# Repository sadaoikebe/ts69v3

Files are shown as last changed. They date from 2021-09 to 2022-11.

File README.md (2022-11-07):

# TS69V3 親指シフト入力に使える一体型 65% キーボード

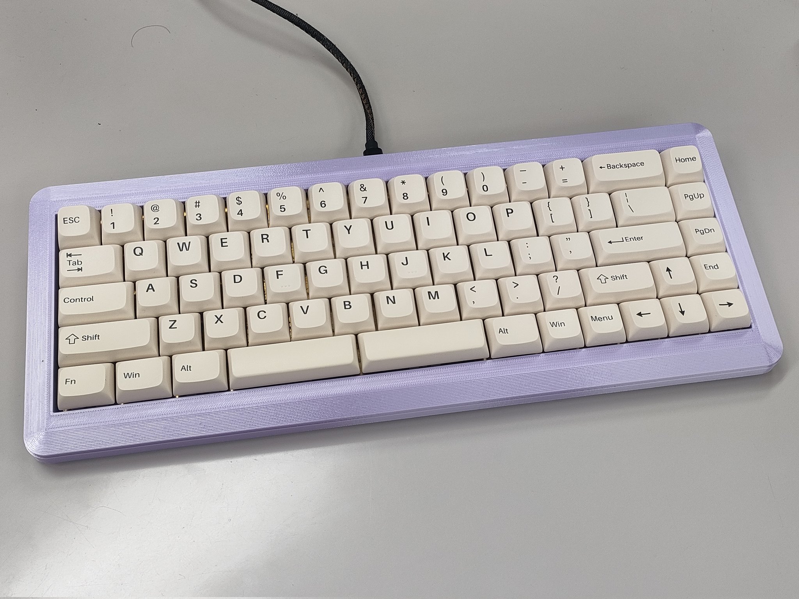
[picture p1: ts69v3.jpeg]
TS69V3


## 特徴

オープンソースの親指シフトキーボードです。

* オープンソース基板（誰でもJLCPCBでオーダー可能！）
* 3Dプリントケース（誰でもJLCPCBで略）
* 一般的なキーボード部品で組み立て可能

## キーボード配列

* US / JP 両対応
* 矢印キーあり
* 対応する親指シフトファームウェアあり [ts69v3 firmware](https://github.com/sadaoikebe/qmk_firmware/tree/master/keyboards/ts69/v3)
* 親指シフト対応、親指キーB下割れ
* 親指キーに3u/2.75u/2.25uのキーキャップの任意の組み合わせが使用できる
* QMK対応

## 物理配列

本PCBで対応する物理配列を以下で解説します。代表的なものは以下の2通りです。

### US配列
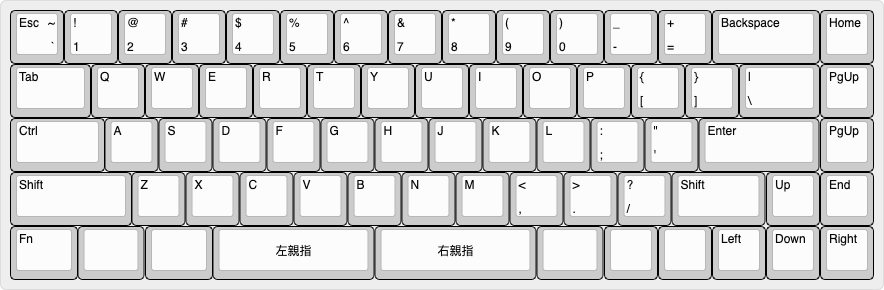
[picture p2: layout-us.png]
US LAYOUT

<!--
["Esc\n\n~\n`","!\n1","@\n2","#\n3","$\n4","%\n5","^\n6","&\n7","*\n8","(\n9",")\n0","_\n-","+\n=",{w:2},"Backspace","Home"],
[{w:1.5},"Tab","Q","W","E","R","T","Y","U","I","O","P","{\n[","}\n]",{w:1.5},"|\n\\","PgUp"],
[{w:1.75},"Ctrl","A","S","D","F","G","H","J","K","L",":\n;","\"\n'",{w:2.25},"Enter","PgUp"],
[{w:2.25},"Shift","Z","X","C","V","B","N","M","<\n,",">\n.","?\n/",{w:1.75},"Shift","Up","End"],
[{a:7,w:1.25},"",{w:1.25},"",{w:1.25},"",{w:3},"3u 左親指",{w:3},"3u 右親指",{w:1.25},"","","","","",""],
-->

### JP配列
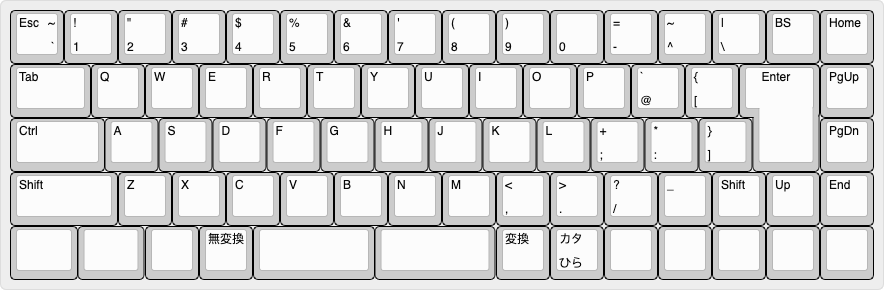
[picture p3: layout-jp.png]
JP LAYOUT
 
<!--
["Esc\n\n~\n`","!\n1","\"\n2","#\n3","$\n4","%\n5","&\n6","'\n7","(\n8",")\n9","\n0","=\n-","~\n^","|\n\\","BS","Home"],
[{w:1.5},"Tab","Q","W","E","R","T","Y","U","I","O","P","`\n@","{\n[",{x:0.25,w:1.25,h:2,w2:1.5,h2:1,x2:-0.25},"Enter","PgUp"],
[{w:1.75},"Ctrl","A","S","D","F","G","H","J","K","L","+\n;","*\n:","}\n]",{x:1.25},"PgDn"],
[{w:2},"Shift","Z","X","C","V","B","N","M","<\n,",">\n.","?\n/","_","Shift","Up","End"],
[{w:1.25},"",{w:1.25},"","","無変換",{w:2.25},"",{w:2.25},"","変換","カタ\nひら","","","","",""],
-->
JP配列のキー数を再現する場合、図のようにShiftの行は左に0.25u移動して、2u左小指シフト/1u右小指シフトを使用します。  
2.25u/1.75uの小指シフトを用いたければ、"_"(アンダースコア)のキーをあきらめてFnキー併用などして入力するようにするとよいでしょう。この場合Shiftの行の物理配列はUS配列と同様になります。  

### 親指シフトキーの選択肢

最下段は使用する親指キーの長さにより割り当てを選択できます。
キーキャップセットによっては、含まれるスペースバーの種類に制約があるけど、できるだけ対応できるようにしました。左右で違う長さの親指キーを使うこともできます。  
2.25uを使用すると、キーが一つ増えます。JP配列の場合は無変換や変換キーを割り当てることを想定しています。US配列の場合はお好みのキーを割り当てられます。

US R5 LAYOUT 
<!--
[{a:7,w:1.25},"",{w:1.25},"",{w:1.25},"",{w:3},"3u 左親指",{w:3},"3u 右親指",{w:1.25},"","","","","",""],
[{w:1.25},"",{w:1.25},"",{w:1.5},"",{w:2.75},"2.75u 左親指",{w:2.75},"2.75u 右親指",{w:1.25},"",{w:1.25},"","","","",""],
[{w:1.25},"",{w:1.25},"","","無変換",{w:2.25},"2.25u 左親指",{w:2.25},"2.25u 左親指","変換","","","","","",""]
-->

### 最上段のBackspaceキー

最上段に2u Backspaceを用いるかわりに、2つのキーを割りあてることができます。最上段にBackspaceを割り当てない場合、一般的に上から2段目のキーにBackspaceを割り当てるようです。(HHKB-likeなレイアウトです)

US R1 LAYOUT
<!--
["Esc\n\n~\n`","!\n1","@\n2","#\n3","$\n4","%\n5","^\n6","&\n7","*\n8","(\n9",")\n0","_\n-","+\n=",{w:2},"Backspace","Home"],
["Esc","!\n1","@\n2","#\n3","$\n4","%\n5","^\n6","&\n7","*\n8","(\n9",")\n0","_\n-","+\n=","|\n\\","~\n`","Home"],
-->

# BOM

Item |ソース | 数量 |  備考
:--- | :--- | :--- | :---
TS69V3 PCBA | [JLCPCB PCBA](pcb/) | 1 |
ケース | [3D Printed](case/) | 1 | 
定位板 | [Laser Cut Brass](plate/) | 1 | t=1.5mm アクリルでも良いが割れやすい
ヒートセット M3x6mmx4.6mm | [AliEx/淘宝等](https://www.aliexpress.com/item/1005002288716120.html) | 10 | 長さは6mmでなくても良い
M3 円頭六角ボルト 6mm | | 10 |  
クッション 2mm厚 x 60mm x 4mm | | 16 | Poron/EVAフォーム等
Pro Micro | [Shigezone等](https://www.shigezone.com/product/arduino-pro-micro/) | 1 | USB-Cタイプがおすすめ
ピンヘッダ 12pin 2.54ピッチ | 電子工作ショップ等 | 2 |
キースイッチ | AliEx/淘宝/自キ専門店等 | 配列によって69〜73個 | 何でもOK(kailh box 白軸がおすすめ)
2u スタビライザー | AliEx/淘宝/自キ専門店等 | 配列によって2〜5個 | 採用したPlateの種類に応じて Plate Mount / PCB Mountを選択
3u スタビライザー | AliEx/淘宝/自キ専門店等 | 配列によって0〜2個 | 
キーキャップ | AliEx/淘宝/自キ専門店等 | 1set | 3u/2.75u/2.25u等の親指キーが計2つ必要

## 組み立て工程

Pro Microを裏側実装する関係で、実装の順番を間違えると*かなり*面倒
1. 基板にスタビライザーを取り付け
2. 基板にピンヘッダを半田付け
3. 定位板に四隅のキースイッチを通す。Pro Microを実装する面の裏のキー(ESCと1)は2つともキースイッチをハンダ付けする。(以後取り外しが極めて難しい)
4. Pro Microを取り付け、キースイッチを取り付け

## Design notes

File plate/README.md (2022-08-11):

# TC69V3 Plate

真鍮板やアクリル板等のレーザーカットを想定。PLA等での成形も可

t=1.5mm (金属) or t=4mm (プラスチック)

### Plate Mount

プレートマウント型のスタビライザーを使う関係で親指キー 3u/2.75u のキーキャップのみ対応している。

[Plate Mount](ts69v3_plate_platemounted.dxf) 

### PCB Mount

PCB側のスタビライザーソケットを使うので、各種親指キーに対応。 過去にTinkercadで開発したため現在ソースファイルなし。(以後FreeCadに移行予定)

[PCB Mount](ts69v3_plate_pcbmounted.dxf)

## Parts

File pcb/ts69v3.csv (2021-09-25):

Comment | Designator | Footprint | LCSC
0.1u | C8,C9,C10,C11,C12,C13,C14,C15,C16,C17,C18 | Capacitor_SMD:C_0402_1005Metric | C60474
D | D1,D2,D3,D4,D5,D6,D7,D8,D9,D10,D11,D12,D13,D14,D15,D16,D17,D18,D19,D20,D21,D22,D23,D24,D25,D26,D27,D28,D29,D30,D31,D32,D33,D34,D35,D36,D37,D38,D39,D40,D41,D42,D43,D44,D45,D46,D47,D48,D49,D50,D51,D52,D53,D54,D55,D56,D57,D58,D59,D60,D61,D62,D63,D64,D65,D66,D67,D68,D69,D70,D71,D72,D85,D87,D88 | Diode_SMD:D_SOD-123 | C2099
WS2812B | D74,D75,D76,D77,D78,D79,D80,D81,D82,D83,D84 | LED_SMD:LED_WS2812B_PLCC4_5.0x5.0mm_P3.2mm | C114586

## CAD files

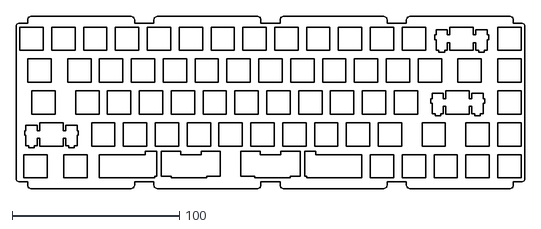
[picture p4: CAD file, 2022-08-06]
plate/ts69v3_plate_pcbmounted.dxf
304.0 x 103.0

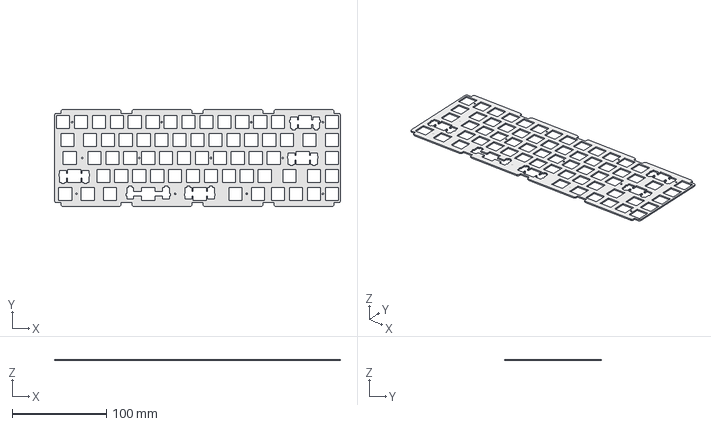
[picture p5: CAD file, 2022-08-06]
plate/plate.FCStd
304.0 x 103.0 x 1.50 mm

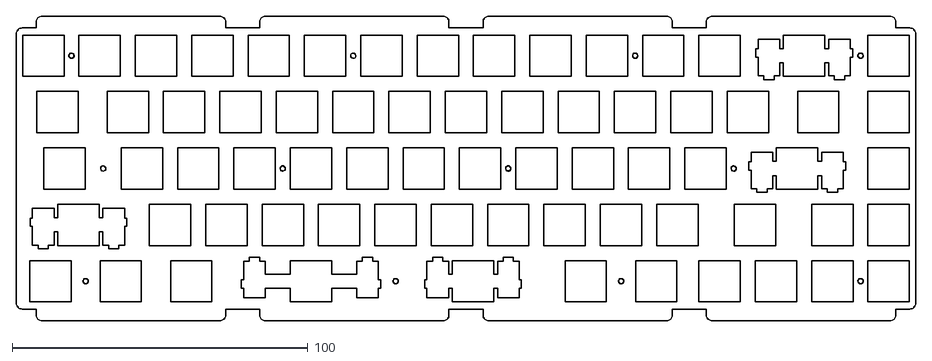
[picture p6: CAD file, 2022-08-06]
plate/ts69v3_plate_platemounted.dxf
304.0 x 103.0

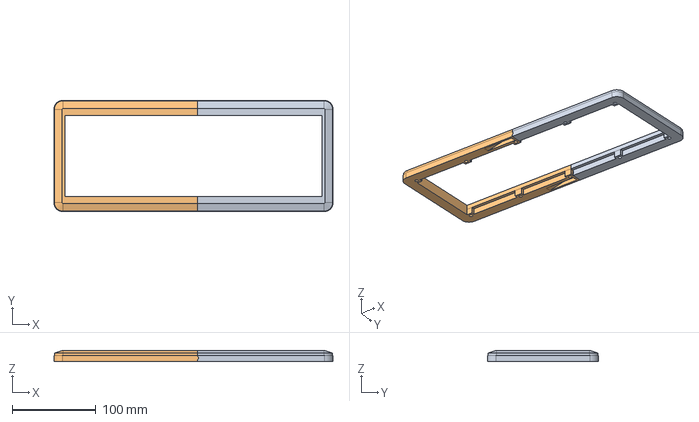
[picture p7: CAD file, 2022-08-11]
case/ts69-case.FCStd
333.0 x 132.5 x 13.0 mm
Lid-R
Lid-L

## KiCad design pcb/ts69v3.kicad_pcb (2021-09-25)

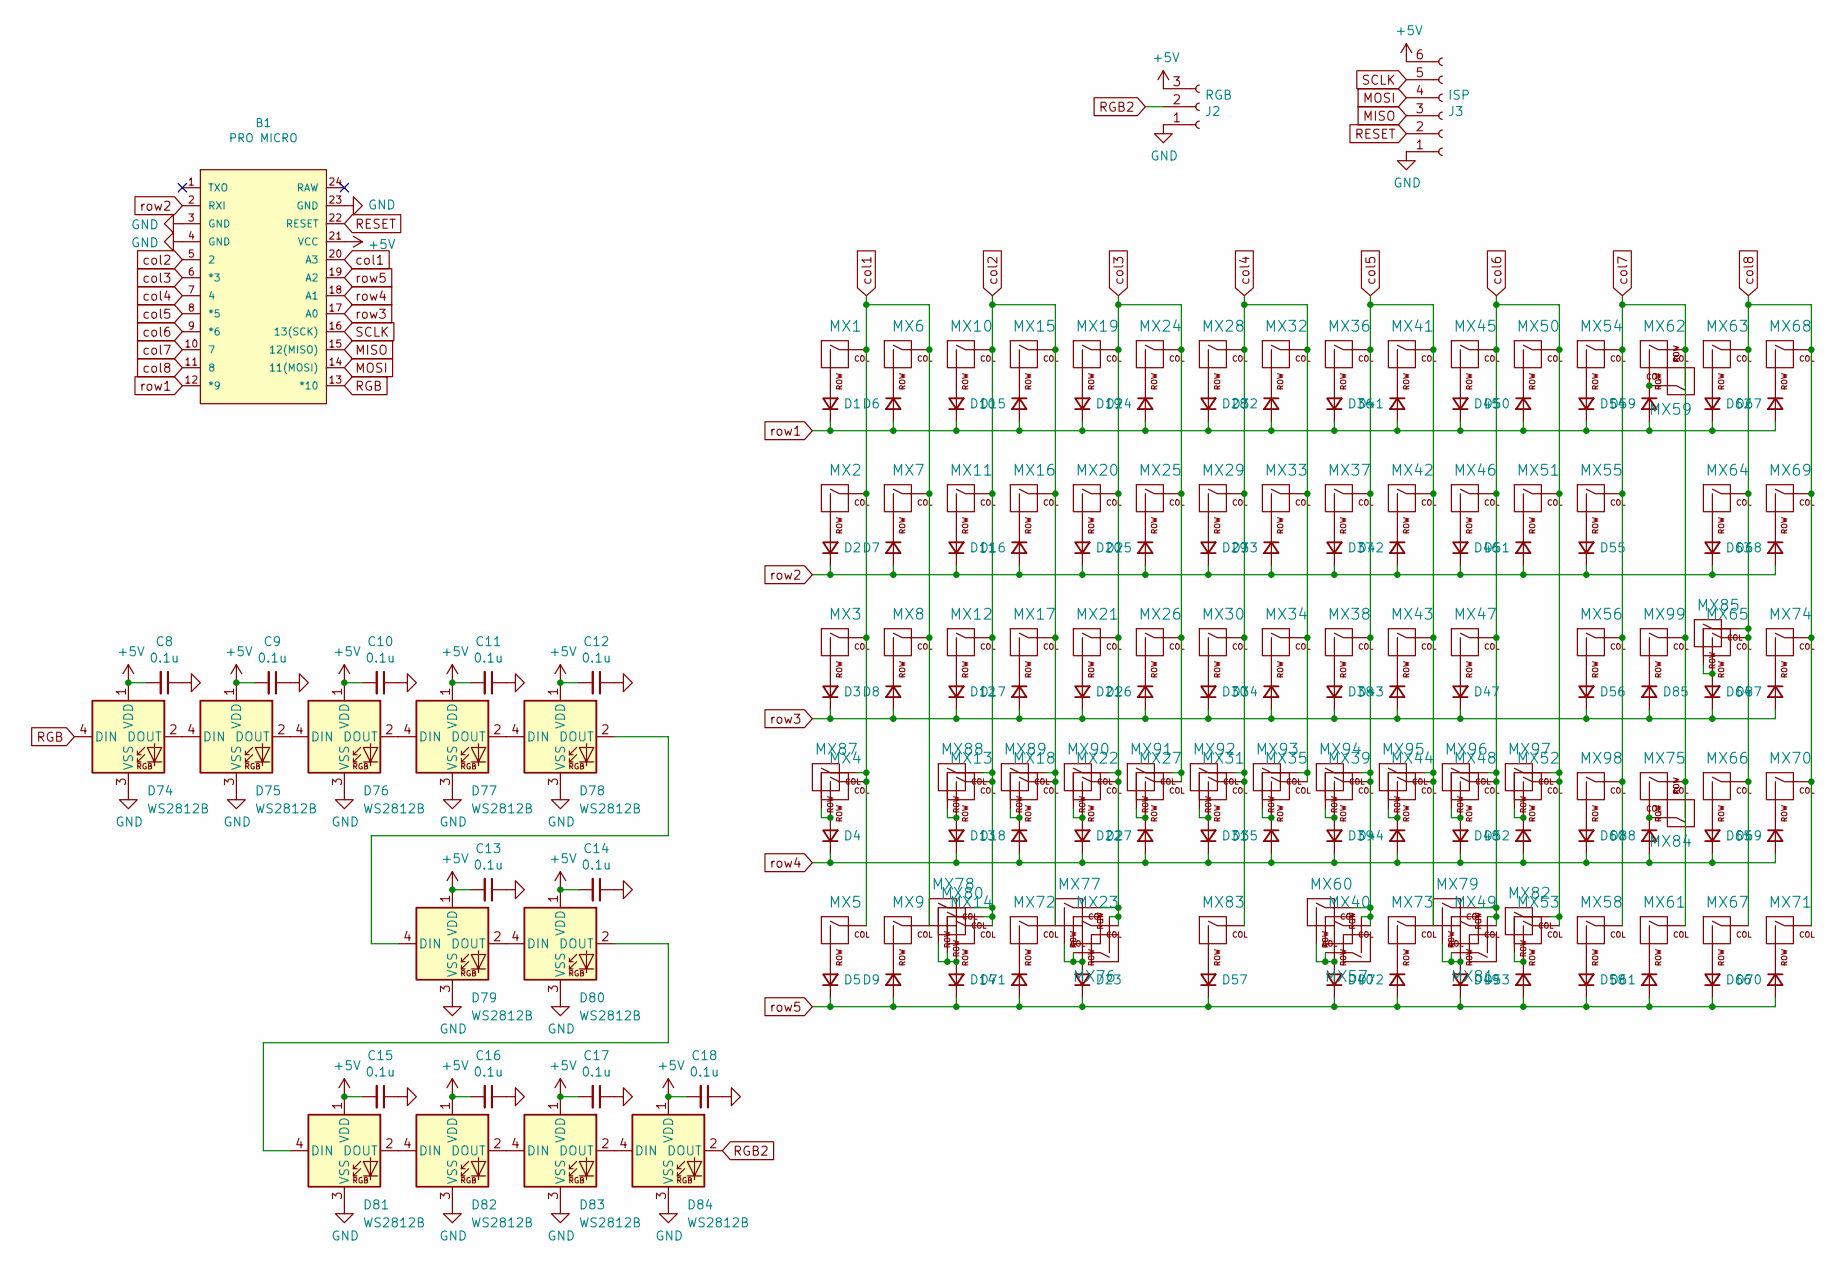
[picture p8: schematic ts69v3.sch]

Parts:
B1: PRO MICRO; PROMICRO_CONTHRU
C8, C9, C10, C11, C12, C13, C14, C15, C16, C17, C18: 0.1u; C_0402_1005Metric; LCSC C60474
D1, D2, D3, D4, D5, D6, D7, D8, D9, D10, D11, D12, D13, D14, D15, D16, D17, D18, D19, D20, D21, D22, D23, D24, D25, D26, D27, D28, D29, D30, D31, D32, D33, D34, D35, D36, D37, D38, D39, D40, D41, D42, D43, D44, D45, D46, D47, D48, D49, D50, D51, D52, D53, D54, D55, D56, D57, D58, D59, D60, D61, D62, D63, D64, D65, D66, D67, D68, D69, D70, D71, D72, D85, D87, D88: D; D_SOD-123; LCSC C2099
D74, D75, D76, D77, D78, D79, D80, D81, D82, D83, D84: WS2812B; LED_WS2812B_PLCC4_5.0x5.0mm_P3.2mm; LCSC C114586
J2: RGB; PinHeader_1x03_P2.00mm_Vertical
J3: ISP; PinHeader_1x06_P2.00mm_Vertical
MX1, MX6, MX7, MX8, MX10, MX11, MX12, MX13, MX15, MX16, MX17, MX18, MX19, MX20, MX21, MX22, MX24, MX25, MX26, MX27, MX28, MX29, MX30, MX31, MX32, MX33, MX34, MX35, MX36, MX37, MX38, MX39, MX41, MX42, MX43, MX44, MX45, MX46, MX47, MX48, MX50, MX51, MX52, MX53, MX54, MX55, MX56, MX58, MX59, MX61, MX63, MX66, MX67, MX68, MX69, MX70, MX71, MX72, MX73, MX74, MX79, MX80, MX84, MX88, MX89, MX90, MX91, MX92, MX93, MX94, MX95, MX96, MX97, MX98, MX99: MX-NoLED; MXOnly-1U-NoLED
MX2, MX64, MX78: MX-NoLED; MXOnly-1.5U-NoLED
MX3, MX75: MX-NoLED; MXOnly-1.75U-NoLED
MX4, MX65: MX-NoLED; MXOnly-2.25U-NoLED
MX5, MX9, MX14, MX49, MX81, MX82: MX-NoLED; MXOnly-1.25U-NoLED
MX23, MX40: MX-NoLED; MXOnly-3U-ReversedStabilizers-NoLED
MX57, MX76: MX-NoLED; MXOnly-2.25U-ReversedStabilizers-NoLED
MX60, MX77: MX-NoLED; MXOnly-2.75U-ReversedStabilizers-NoLED
MX62, MX87: MX-NoLED; MXOnly-2U-NoLED
MX83: MX-NoLED; MXOnly-6.25U-ReversedStabilizers-NoLED
MX85: MX-NoLED; MXOnly-2U-ReversedVerticalStabilizers-NoLED

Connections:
+5V: B1.21 (VCC), C8.2, C9.2, C10.2, C11.2, C12.2, C13.2, C14.2, C15.2, C16.2, C17.2, C18.2, D74.1 (VDD), D75.1 (VDD), D76.1 (VDD), D77.1 (VDD), D78.1 (VDD), D79.1 (VDD), D80.1 (VDD), D81.1 (VDD), D82.1 (VDD), D83.1 (VDD), D84.1 (VDD), J2.3, J3.6
GND: B1.3 (GND), B1.4 (GND), B1.23 (GND), C8.1, C9.1, C10.1, C11.1, C12.1, C13.1, C14.1, C15.1, C16.1, C17.1, C18.1, D74.3 (VSS), D75.3 (VSS), D76.3 (VSS), D77.3 (VSS), D78.3 (VSS), D79.3 (VSS), D80.3 (VSS), D81.3 (VSS), D82.3 (VSS), D83.3 (VSS), D84.3 (VSS), J2.1, J3.1
MISO: B1.15 (12(MISO)), J3.3
MOSI: B1.14 (11(MOSI)), J3.4
unnamed: D1.2 (A), MX1.2 (ROW)
unnamed: D2.2 (A), MX2.2 (ROW)
unnamed: D3.2 (A), MX3.2 (ROW)
unnamed: D4.2 (A), MX4.2 (ROW), MX87.2 (ROW)
unnamed: D5.2 (A), MX5.2 (ROW)
unnamed: D6.1 (K), MX6.2 (ROW)
unnamed: D7.1 (K), MX7.2 (ROW)
unnamed: D8.1 (K), MX8.2 (ROW)
unnamed: D9.1 (K), MX9.2 (ROW)
unnamed: D10.2 (A), MX10.2 (ROW)
unnamed: D11.2 (A), MX11.2 (ROW)
unnamed: D12.2 (A), MX12.2 (ROW)
unnamed: D13.2 (A), MX13.2 (ROW), MX88.2 (ROW)
unnamed: D14.2 (A), MX14.2 (ROW), MX78.2 (ROW), MX80.2 (ROW)
unnamed: D15.1 (K), MX15.2 (ROW)
unnamed: D16.1 (K), MX16.2 (ROW)
unnamed: D17.1 (K), MX17.2 (ROW)
unnamed: D18.1 (K), MX18.2 (ROW), MX89.2 (ROW)
unnamed: D19.2 (A), MX19.2 (ROW)
unnamed: D20.2 (A), MX20.2 (ROW)
unnamed: D21.2 (A), MX21.2 (ROW)
unnamed: D22.2 (A), MX22.2 (ROW), MX90.2 (ROW)
unnamed: D23.2 (A), MX23.2 (ROW), MX76.1 (COL), MX77.2 (ROW)
unnamed: D24.1 (K), MX24.2 (ROW)
unnamed: D25.1 (K), MX25.2 (ROW)
unnamed: D26.1 (K), MX26.2 (ROW)
unnamed: D27.1 (K), MX27.2 (ROW), MX91.2 (ROW)
unnamed: D28.2 (A), MX28.2 (ROW)
unnamed: D29.2 (A), MX29.2 (ROW)
unnamed: D30.2 (A), MX30.2 (ROW)
unnamed: D31.2 (A), MX31.2 (ROW), MX92.2 (ROW)
unnamed: D32.1 (K), MX32.2 (ROW)
unnamed: D33.1 (K), MX33.2 (ROW)
unnamed: D34.1 (K), MX34.2 (ROW)
unnamed: D35.1 (K), MX35.2 (ROW), MX93.2 (ROW)
unnamed: D36.2 (A), MX36.2 (ROW)
unnamed: D37.2 (A), MX37.2 (ROW)
unnamed: D38.2 (A), MX38.2 (ROW)
unnamed: D39.2 (A), MX39.2 (ROW), MX94.2 (ROW)
unnamed: D40.2 (A), MX40.2 (ROW), MX57.1 (COL), MX60.2 (ROW)
unnamed: D41.1 (K), MX41.2 (ROW)
unnamed: D42.1 (K), MX42.2 (ROW)
unnamed: D43.1 (K), MX43.2 (ROW)
unnamed: D44.1 (K), MX44.2 (ROW), MX95.2 (ROW)
unnamed: D45.2 (A), MX45.2 (ROW)
unnamed: D46.2 (A), MX46.2 (ROW)
unnamed: D47.2 (A), MX47.2 (ROW)
unnamed: D48.2 (A), MX48.2 (ROW), MX96.2 (ROW)
unnamed: D49.2 (A), MX49.2 (ROW), MX79.2 (ROW), MX81.1 (COL)
unnamed: D50.1 (K), MX50.2 (ROW)
unnamed: D51.1 (K), MX51.2 (ROW)
unnamed: D52.1 (K), MX52.2 (ROW), MX97.2 (ROW)
unnamed: D53.1 (K), MX53.2 (ROW), MX82.2 (ROW)
unnamed: D54.2 (A), MX54.2 (ROW)
unnamed: D55.2 (A), MX55.2 (ROW)
unnamed: D56.2 (A), MX56.2 (ROW)
unnamed: D57.2 (A), MX83.2 (ROW)
unnamed: D58.2 (A), MX58.2 (ROW)
unnamed: D59.1 (K), MX59.1 (COL), MX62.2 (ROW)
unnamed: D60.2 (A), MX98.2 (ROW)
unnamed: D61.1 (K), MX61.2 (ROW)
unnamed: D62.2 (A), MX63.2 (ROW)
unnamed: D63.2 (A), MX64.2 (ROW)
unnamed: D64.2 (A), MX65.2 (ROW), MX85.2 (ROW)
unnamed: D65.2 (A), MX66.2 (ROW)
unnamed: D66.2 (A), MX67.2 (ROW)
unnamed: D67.1 (K), MX68.2 (ROW)
unnamed: D68.1 (K), MX69.2 (ROW)
unnamed: D69.1 (K), MX70.2 (ROW)
unnamed: D70.1 (K), MX71.2 (ROW)
unnamed: D71.1 (K), MX72.2 (ROW)
unnamed: D72.1 (K), MX73.2 (ROW)
unnamed: D74.2 (DOUT), D75.4 (DIN)
unnamed: D75.2 (DOUT), D76.4 (DIN)
unnamed: D76.2 (DOUT), D77.4 (DIN)
unnamed: D77.2 (DOUT), D78.4 (DIN)
unnamed: D78.2 (DOUT), D79.4 (DIN)
unnamed: D79.2 (DOUT), D80.4 (DIN)
unnamed: D80.2 (DOUT), D81.4 (DIN)
unnamed: D81.2 (DOUT), D82.4 (DIN)
unnamed: D82.2 (DOUT), D83.4 (DIN)
unnamed: D83.2 (DOUT), D84.4 (DIN)
unnamed: D85.1 (K), MX99.2 (ROW)
unnamed: D87.1 (K), MX74.2 (ROW)
unnamed: D88.1 (K), MX75.2 (ROW), MX84.1 (COL)
RESET: B1.22 (RESET), J3.2
RGB: B1.13 (*10), D74.4 (DIN)
RGB2: D84.2 (DOUT), J2.2
SCLK: B1.16 (13(SCK)), J3.5
col1: B1.20 (A3), MX1.1 (COL), MX2.1 (COL), MX3.1 (COL), MX4.1 (COL), MX5.1 (COL), MX6.1 (COL), MX7.1 (COL), MX8.1 (COL), MX9.1 (COL), MX87.1 (COL)
col2: B1.5 (2), MX10.1 (COL), MX11.1 (COL), MX12.1 (COL), MX13.1 (COL), MX14.1 (COL), MX15.1 (COL), MX16.1 (COL), MX17.1 (COL), MX18.1 (COL), MX72.1 (COL), MX78.1 (COL), MX80.1 (COL), MX88.1 (COL), MX89.1 (COL)
col3: B1.6 (*3), MX19.1 (COL), MX20.1 (COL), MX21.1 (COL), MX22.1 (COL), MX23.1 (COL), MX24.1 (COL), MX25.1 (COL), MX26.1 (COL), MX27.1 (COL), MX76.2 (ROW), MX77.1 (COL), MX90.1 (COL), MX91.1 (COL)
col4: B1.7 (4), MX28.1 (COL), MX29.1 (COL), MX30.1 (COL), MX31.1 (COL), MX32.1 (COL), MX33.1 (COL), MX34.1 (COL), MX35.1 (COL), MX83.1 (COL), MX92.1 (COL), MX93.1 (COL)
col5: B1.8 (*5), MX36.1 (COL), MX37.1 (COL), MX38.1 (COL), MX39.1 (COL), MX40.1 (COL), MX41.1 (COL), MX42.1 (COL), MX43.1 (COL), MX44.1 (COL), MX57.2 (ROW), MX60.1 (COL), MX73.1 (COL), MX94.1 (COL), MX95.1 (COL)
col6: B1.9 (*6), MX45.1 (COL), MX46.1 (COL), MX47.1 (COL), MX48.1 (COL), MX49.1 (COL), MX50.1 (COL), MX51.1 (COL), MX52.1 (COL), MX53.1 (COL), MX79.1 (COL), MX81.2 (ROW), MX82.1 (COL), MX96.1 (COL), MX97.1 (COL)
col7: B1.10 (7), MX54.1 (COL), MX55.1 (COL), MX56.1 (COL), MX58.1 (COL), MX59.2 (ROW), MX61.1 (COL), MX62.1 (COL), MX75.1 (COL), MX84.2 (ROW), MX98.1 (COL), MX99.1 (COL)
col8: B1.11 (8), MX63.1 (COL), MX64.1 (COL), MX65.1 (COL), MX66.1 (COL), MX67.1 (COL), MX68.1 (COL), MX69.1 (COL), MX70.1 (COL), MX71.1 (COL), MX74.1 (COL), MX85.1 (COL)
row1: B1.12 (*9), D1.1 (K), D6.2 (A), D10.1 (K), D15.2 (A), D19.1 (K), D24.2 (A), D28.1 (K), D32.2 (A), D36.1 (K), D41.2 (A), D45.1 (K), D50.2 (A), D54.1 (K), D59.2 (A), D62.1 (K), D67.2 (A)
row2: B1.2 (RXI), D2.1 (K), D7.2 (A), D11.1 (K), D16.2 (A), D20.1 (K), D25.2 (A), D29.1 (K), D33.2 (A), D37.1 (K), D42.2 (A), D46.1 (K), D51.2 (A), D55.1 (K), D63.1 (K), D68.2 (A)
row3: B1.17 (A0), D3.1 (K), D8.2 (A), D12.1 (K), D17.2 (A), D21.1 (K), D26.2 (A), D30.1 (K), D34.2 (A), D38.1 (K), D43.2 (A), D47.1 (K), D56.1 (K), D64.1 (K), D85.2 (A), D87.2 (A)
row4: B1.18 (A1), D4.1 (K), D13.1 (K), D18.2 (A), D22.1 (K), D27.2 (A), D31.1 (K), D35.2 (A), D39.1 (K), D44.2 (A), D48.1 (K), D52.2 (A), D60.1 (K), D65.1 (K), D69.2 (A), D88.2 (A)
row5: B1.19 (A2), D5.1 (K), D9.2 (A), D14.1 (K), D23.1 (K), D40.1 (K), D49.1 (K), D53.2 (A), D57.1 (K), D58.1 (K), D61.2 (A), D66.1 (K), D70.2 (A), D71.2 (A), D72.2 (A)

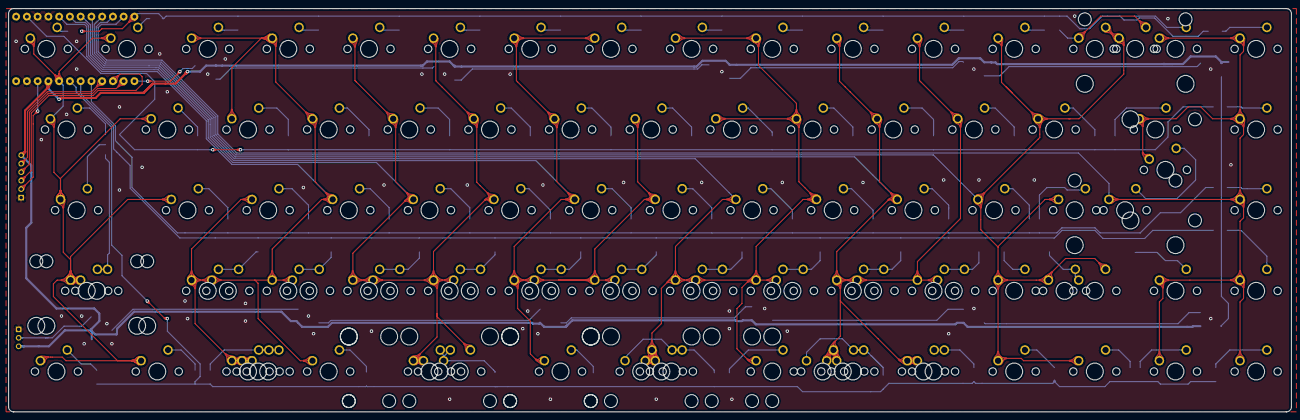
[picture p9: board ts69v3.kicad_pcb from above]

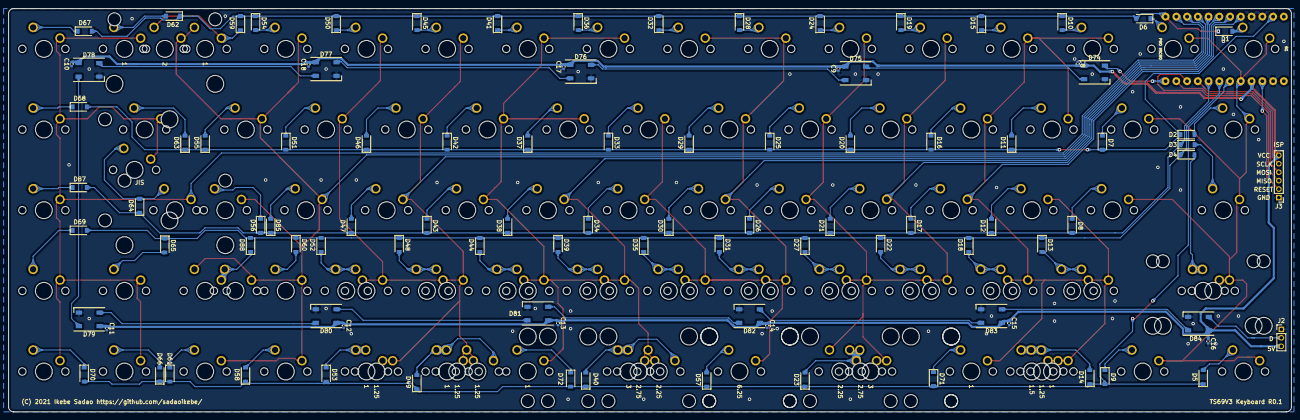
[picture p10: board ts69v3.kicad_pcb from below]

Board: 2 copper layers, 303.0 x 95.3 mm, 198 parts (100 on the bottom side), 106 nets.

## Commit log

2021-09-25 jlcpcb order
    [ts69v3-B_Cu.gbl, ts69v3-B_Mask.gbs, ts69v3-B_Paste.gbp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]
2021-09-25 add readme, move to subdirectory
    [ts69v3-B_Cu.gbl, ts69v3-B_Mask.gbs, ts69v3-B_Paste.gbp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]
2022-08-06 add bom table
2022-08-06 fix bom table
2022-08-06 added cusion to BOM
2022-08-06 fix bom
2022-08-06 add plate
    [plate.FCStd, ts69v3_plate_pcbmounted.dxf, ts69v3_plate_platemounted.dxf]
2022-08-06 fix dxf scale
    [ts69v3_plate_pcbmounted.dxf]
2022-08-10 add case
    [ts69-case.FCStd]
2022-08-10 add case link
2022-08-11 add case stl and plate thickness
    [ts69-case-Base.stl, ts69-case-Lid.stl, ts69-case.FCStd]
2022-08-11 separate lid
    [ts69-case-Lid-L.stl, ts69-case-Lid-R.stl, ts69-case.FCStd]
2022-08-11 add separate base
    [ts69-case-Base-L.stl, ts69-case-Base-R.stl, ts69-case-Lid-L.stl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]
2022-08-11 base depth and split groove
    [ts69-case-Base-L.stl, ts69-case-Base-R.stl, ts69-case-Base.stl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]
2022-08-11 depth adjustment
    [ts69-case-Base-L.stl, ts69-case-Base-R.stl, ts69-case-Base.stl]
2022-08-11 old logo remnant
    [ts69-case-Base-R.stl]
2022-08-12 change rubber preload
    [ts69-case-Base-L.stl, ts69-case-Base-R.stl, ts69-case-Base.stl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]
2022-08-28 bom update

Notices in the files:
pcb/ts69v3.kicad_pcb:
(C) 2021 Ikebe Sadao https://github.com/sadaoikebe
